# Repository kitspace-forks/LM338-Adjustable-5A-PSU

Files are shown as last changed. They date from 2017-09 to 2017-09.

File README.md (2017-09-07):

# LM338 1.8V-30V 5A Linear PSU

This repository contains EagleCAD PCB files for a 5 Amp adjustable voltage linear power supply using the LM338 IC. Output is adjustable between 1.8V and 30V; the input voltage must be at least 5V above the desired output voltage. Theoretically the design is capable of up to 150 watts power, but the LM338 will require proper cooling.

This design is based on the _Adjustable Regulator With Improved Ripple Rejection_ design found on page 18 of the Texas Instruments LM338 [datasheet](http://www.ti.com/lit/ds/symlink/lm338.pdf).

This work was originally created in 2013 but is now being published here under the MIT licence.

## More Information

See: https://devtty.io/2017/09/electronics/lm338-linear-voltage-regulator-pcb/

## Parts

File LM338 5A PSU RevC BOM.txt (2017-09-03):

Partlist exported from D:/My Documents/Documents/Electronics/EAGLE/Project Files/PCB002 - LM338 PSU/RevC/LM338 PSU RevC.sch at 03/09/2017 09:27

Part     Value                  Device                 Package            Description                                         MF                           MPN                OC_FARNELL OC_NEWARK PACKAGE        PCB_SIZE  SUPPLIER  TOLERANCE TP_SIGNAL_NAME VALUE  VOLTAGERATING
C1       1000UF                 ECA1HHG102-D12.5XP5    CAPPR500-1250X2500 Aluminum Electrolytic Capacitors/Radial Lead Type   PANASONIC                    ECA1HM102          9693823    96K9163   Radial Lead-TH           PANASONIC ±20 %                    1000UF 50V          
C2       1uF.T                  CPOL-EUE5-4            E5-4               POLARIZED CAPACITOR, European symbol                                                                unknown                                                                                              
C3       10uF                   CPOL-EUE2.5-7          E2,5-7             POLARIZED CAPACITOR, European symbol                PANASONIC                    ECEA1HN100U        9696636                                                                                              
C4       1uF.T                  CPOL-EUE5-4            E5-4               POLARIZED CAPACITOR, European symbol                                                                unknown                                                                                              
C5       10uF                   CPOL-EUE2.5-7          E2,5-7             POLARIZED CAPACITOR, European symbol                PANASONIC                    ECEA1HN100U        9696636                                                                                              
C6       0.1uF                  C-EU025-025X050        C025-025X050       CAPACITOR, European symbol                          AVX                          02016D104KAT2A     1657913                                                                                              
D1       1N4002                 1N4004                 DO41-10            DIODE                                               ON SEMICONDUCTOR             1N4002RLG          1264225                                                                                              
D2       1N4002                 1N4004                 DO41-10            DIODE                                               ON SEMICONDUCTOR             1N4002RLG          1264225                                                                                              
FUSE     5A                     PTCPTH                 PTC                Resettable Fuse PTC                                 LITTELFUSE                   30R400UF           1822241                                                                                              
IC1      LM338T                 V_REG_317SINK          TO220-ADJ          Voltage Regulator                                   TEXAS INSTRUMENTS            LM338T/NOPB        1469094                                                                                              
IC2      CL2N3-G                CL2N3-G                TO-92                                                                                                                  unknown                                                                                              
J1                              W237-102               W237-102           WAGO SCREW CLAMP                                    MULTICOMP                    MC000048           2008019    70K9898                                                                                   
J2                              DCBARRELPTH            DCJACK_2MM_PTH     2.0mm DC Barrel Jack                                                                                unknown                                                                                              
J3                              PINHD-2X6              2X06               PIN HEADER                                                                                          unknown                                                                                              
J4                              PINHD-1X3/90           1X03/90            PIN HEADER                                          MULTICOMP                    MC34747            1593427                                                                                              
J5                              PINHD-1X2/90           1X02/90            PIN HEADER                                          MULTICOMP                    MC34745            1593426                                                                                              
J6                              PINHD-1X2/90           1X02/90            PIN HEADER                                          MULTICOMP                    MC34745            1593426                                                                                              
J7                              PINHD-1X2/90           1X02/90            PIN HEADER                                          MULTICOMP                    MC34745            1593426                                                                                              
J8                              W237-102               W237-102           WAGO SCREW CLAMP                                    MULTICOMP                    MC000048           2008019    70K9898                                                                                   
PCB1     PCB_DP_RECTANGLE-43X70 PCB_DP_RECTANGLE-43X70 DP7043_V1          Dangerous Prototypes Standard Rectangular PCB sizes                                                 unknown                             DP7043_V1                                                        
PWR                             LED5MM                 LED5MM             LED                                                 CREE                         C503B-RBN-CX0Y0AA1 1855569                                                                                              
R1       53R6                   R-EU_0207/10           0207/10            RESISTOR, European symbol                           TE CONNECTIVITY / HOLSWORTHY H853R6BYA          1751303                                                                                              
R2       120R                   R-EU_0207/10           0207/10            RESISTOR, European symbol                           WELWYN                       PR5Y-120RBI        1634027                                                                                              
R3       150R                   R-EU_0207/10           0207/10            RESISTOR, European symbol                           TE CONNECTIVITY / HOLSWORTHY H8150RBYA          1751336                                                                                              
R4       200R                   R-EU_0207/10           0207/10            RESISTOR, European symbol                           TE CONNECTIVITY / HOLSWORTHY H8200RBYA          1751365                                                                                              
R5       360R                   R-EU_0207/10           0207/10            RESISTOR, European symbol                           MULTICOMP                    MF25 360R          9341790                                                                                              
R6       750R                   R-EU_0207/10           0207/10            RESISTOR, European symbol                           TE CONNECTIVITY / HOLSWORTHY H8750RBYA          1751430                                                                                              
R7       5K                     TRIMMER-3362P          TRIMMER_3362P      Trimmer resistor                                    BOURNS                       3362P-1-502LF      9354379                                                                                              
R8       120R 0.1%              R-EU_0207/10           0207/10            RESISTOR, European symbol                           MULTICOMP                    MF25 120R          9341218                                                                                              
TEST_GND TPPAD1-13              TPPAD1-13              P1-13              Test pad                                                                                            unknown

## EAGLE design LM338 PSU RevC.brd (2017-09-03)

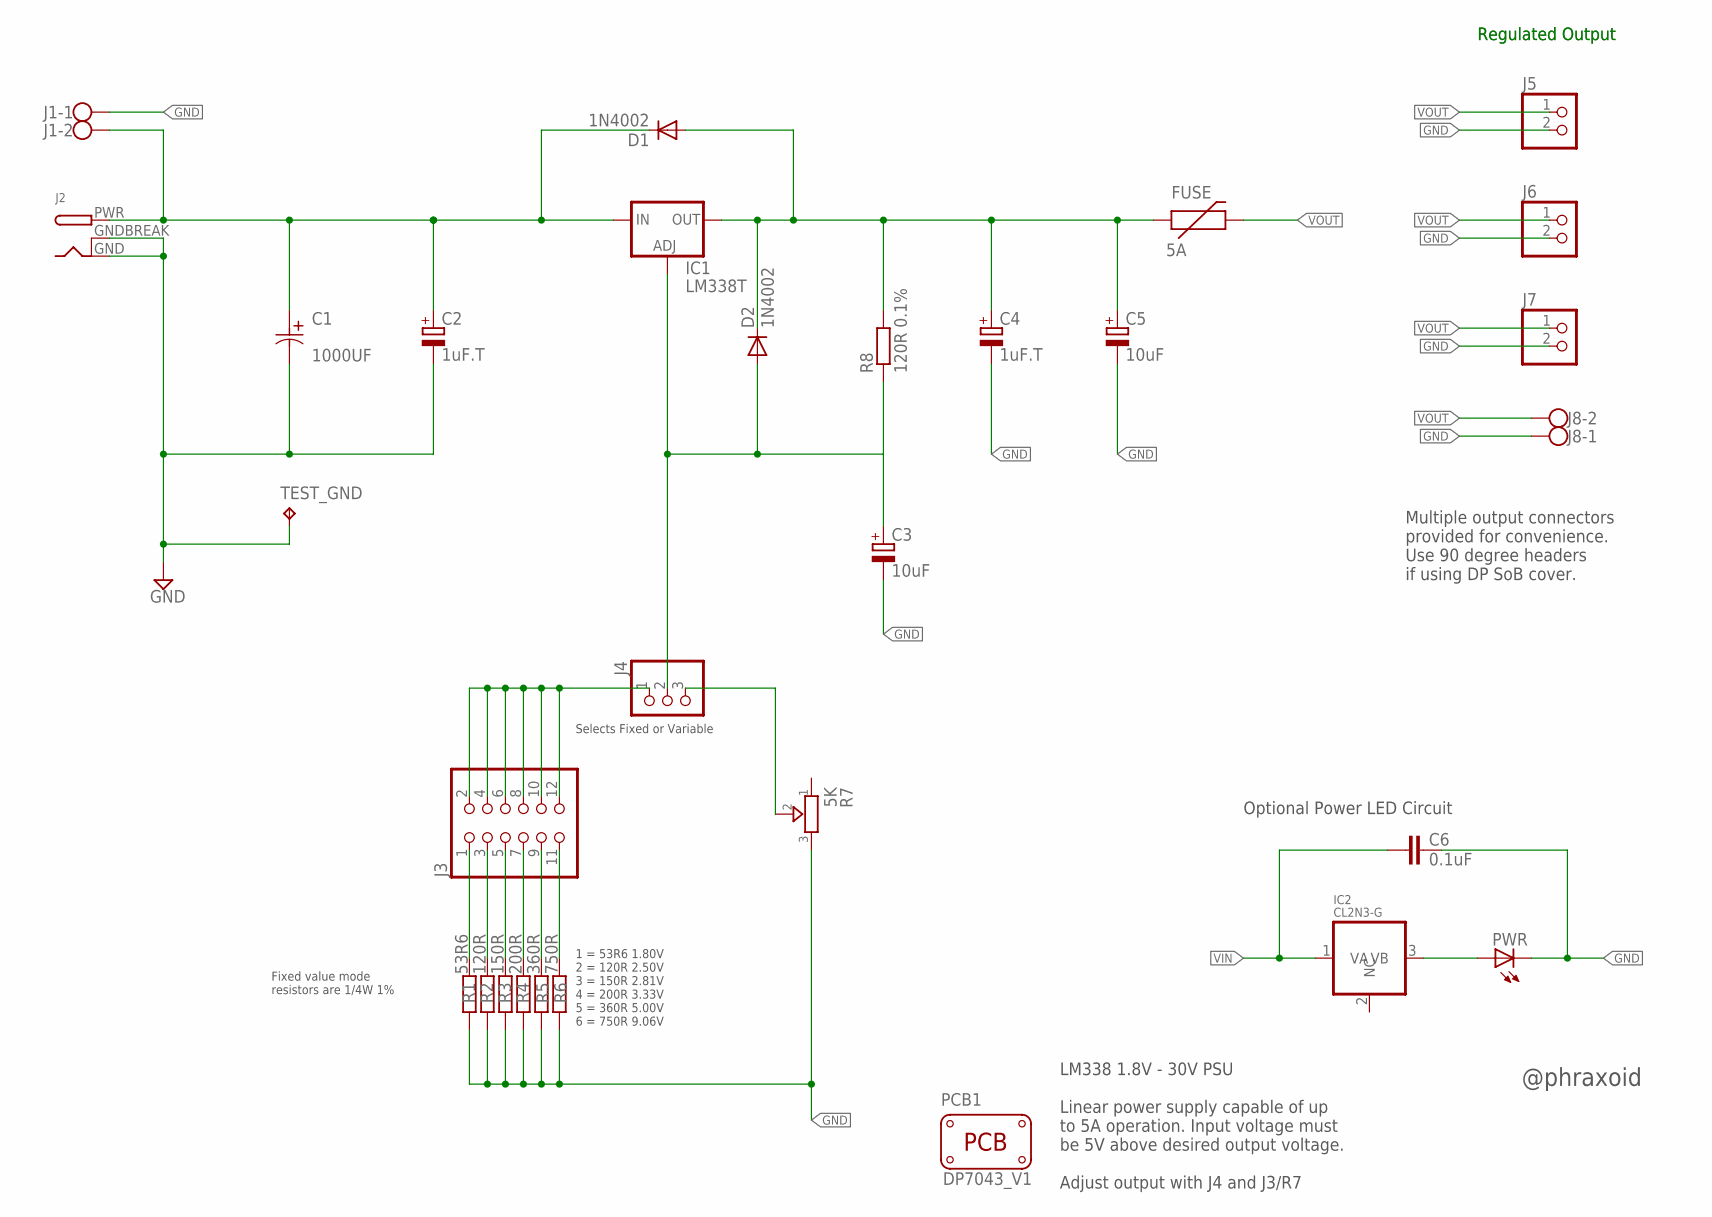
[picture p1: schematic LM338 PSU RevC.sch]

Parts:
C1: 1000UF; CAPPR500-1250X2500; MPN ECA1HM102
C2, C4: 1uF.T; E5-4
C3, C5: 10uF; E2,5-7; MPN ECEA1HN100U
C6: 0.1uF; C025-025X050; MPN 02016D104KAT2A
D1, D2: 1N4002; DO41-10; MPN 1N4002RLG
FUSE: 5A; PTC; MPN 30R400UF
IC1: LM338T; TO220-ADJ; MPN LM338T/NOPB
IC2: CL2N3-G; TO-92
J1, J8: W237-102; MPN MC000048
J2: DCBARRELPTH; DCJACK_2MM_PTH
J3: PINHD-2X6; 2X06
J4: PINHD-1X3/90; 1X03/90; MPN MC34747
J5, J6, J7: PINHD-1X2/90; 1X02/90; MPN MC34745
PCB1: PCB_DP_RECTANGLE-43X70; DP7043_V1
PWR: LED5MM; MPN C503B-RBN-CX0Y0AA1
R1: 53R6; 0207/10; MPN H853R6BYA
R2: 120R; 0207/10; MPN PR5Y-120RBI
R3: 150R; 0207/10; MPN H8150RBYA
R4: 200R; 0207/10; MPN H8200RBYA
R5: 360R; 0207/10; MPN MF25 360R
R6: 750R; 0207/10; MPN H8750RBYA
R7: 5K; TRIMMER_3362P; MPN 3362P-1-502LF
R8: 120R 0.1%; 0207/10; MPN MF25 120R
TEST_GND: TPPAD1-13; P1-13

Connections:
ADJ: C3.+, D2.A, IC1.ADJ, J4.2, R8.1
GND: C1.2, C2.-, C3.-, C4.-, C5.-, C6.2, J1.1, J2.GND, J2.GNDBREAK, J5.2, J6.2, J7.2, J8.1, PWR.K (C), R1.1, R2.1, R3.1, R4.1, R5.1, R6.1, R7.3, TEST_GND.TP
unnamed: J3.2, J3.4, J3.6, J3.8, J3.10, J3.12, J4.1
unnamed: J4.3, R7.2
unnamed: J3.1, R1.2
unnamed: J3.3, R2.2
unnamed: J3.5, R3.2
unnamed: J3.7, R4.2
unnamed: J3.9, R5.2
unnamed: J3.11, R6.2
unnamed: IC2.3 (VB), PWR.A
OUT: C4.+, C5.+, D1.A, D2.C, FUSE.P$1 (1), IC1.OUT, R8.2
VIN: C1.1, C2.+, C6.1, D1.C, IC1.IN, IC2.1 (VA), J1.2, J2.PWR
VOUT: FUSE.P$2 (2), J5.1, J6.1, J7.1, J8.2

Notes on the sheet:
Regulated Output
Multiple output connectors provided for convenience. Use 90 degree headers if using DP SoB cover.
1 = 53R6 1.80V 2 = 120R 2.50V 3 = 150R 2.81V 4 = 200R 3.33V 5 = 360R 5.00V 6 = 750R 9.06V
Fixed value mode resistors are 1/4W 1%
LM338 1.8V - 30V PSU Linear power supply capable of up to 5A operation. Input voltage must be 5V above desired output voltage. Adjust output with J4 and J3/R7
@phraxoid
Optional Power LED Circuit
Selects Fixed or Variable

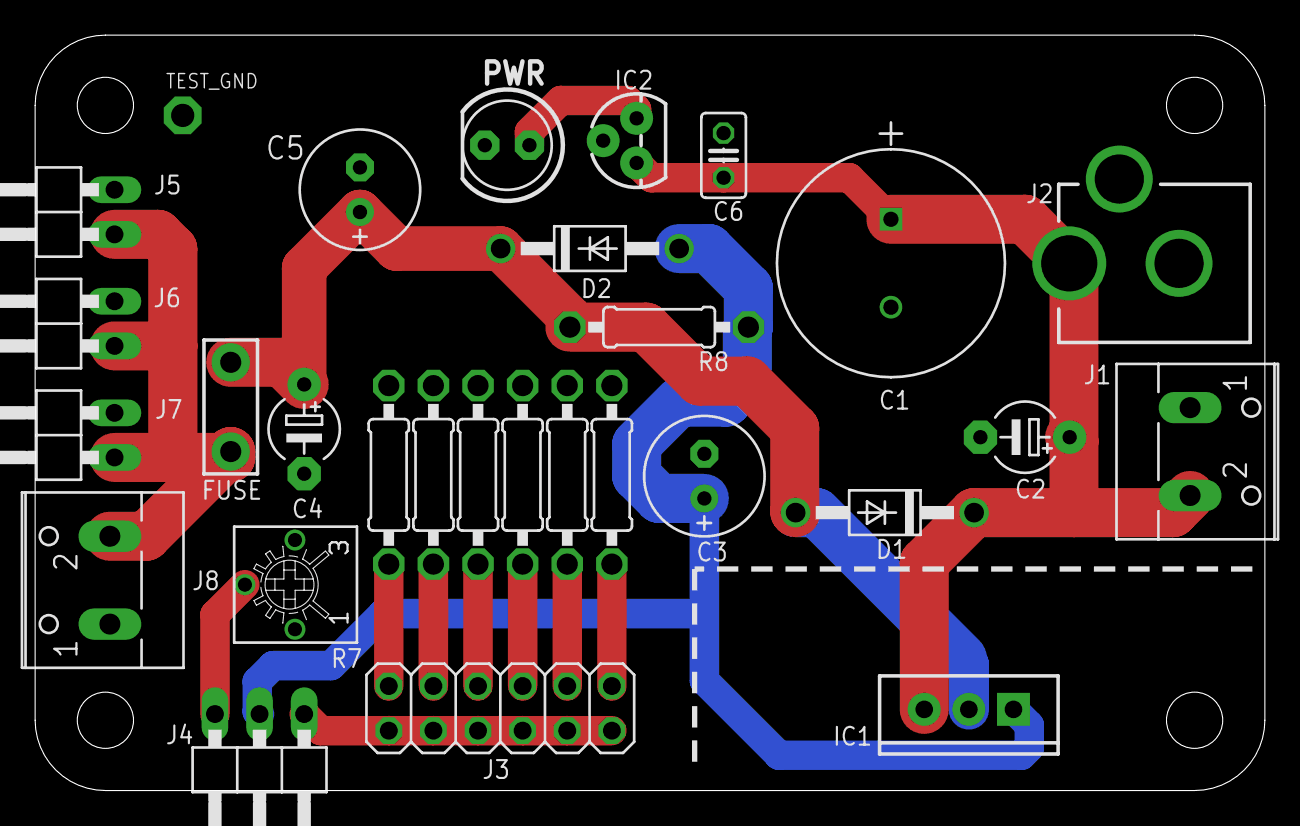
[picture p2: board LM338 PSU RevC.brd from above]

Board: 2 copper layers, 70.0 x 43.0 mm, 30 parts (0 on the bottom side), 14 nets.

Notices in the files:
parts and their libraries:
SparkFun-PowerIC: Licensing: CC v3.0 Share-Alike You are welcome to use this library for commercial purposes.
